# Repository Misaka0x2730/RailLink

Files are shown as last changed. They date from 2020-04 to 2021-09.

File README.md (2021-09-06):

# RailLink
Very compact isolated version of J-Link v9 with fully supported functions. </br>
Isolation based on ADuM4160 (USB2.0 FS isolation) and B0505S-1W (Isolated 5V/0.2A DC-DC). </br>

# Overview
Dimensions(L x W x H, millimeters): 70 x 28 x 15 (probe only); 110 x 35 x 25 (probe with connected adapter). </br>
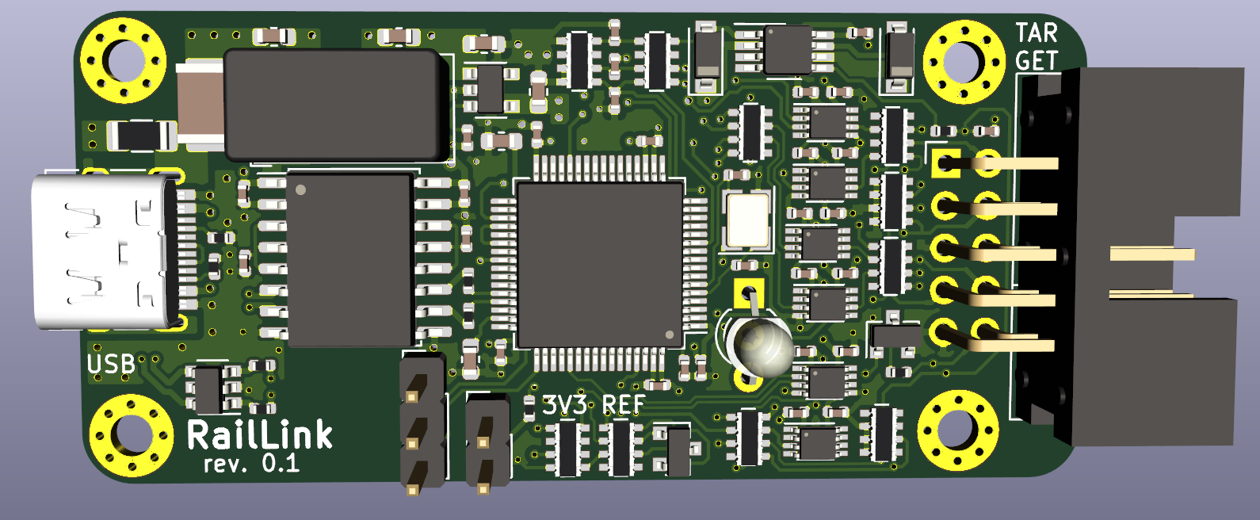
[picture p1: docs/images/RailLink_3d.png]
3d view

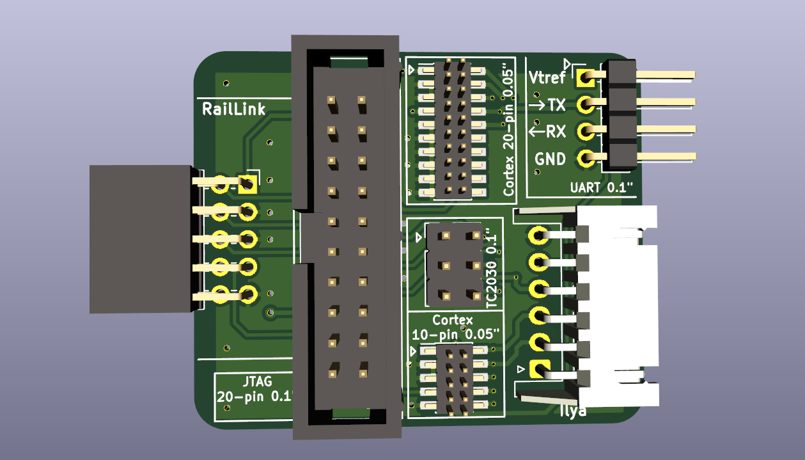
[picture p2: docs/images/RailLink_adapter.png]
3d_adapter


# Probe pinout
RailLink has 10 pin 0.1"(2.54mm) connector compatible with standard ARM 10 pin connector.

<b>RailLink connector</b></br>
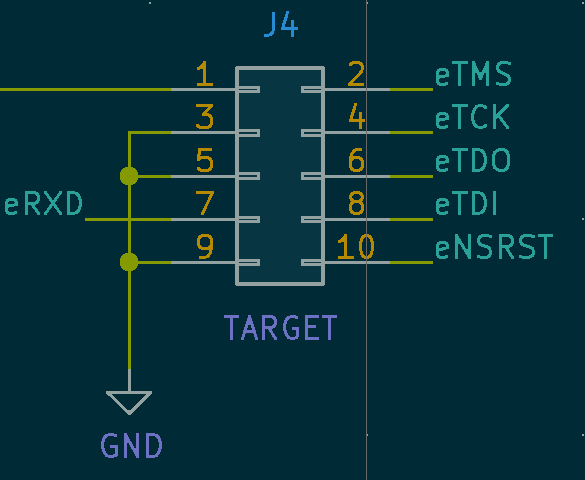
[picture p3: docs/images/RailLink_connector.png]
connector

|Pin|Name |Pin|Name |
|---|---|---|---|
|1  |Vtref  |2  | TMS/SWDIO  |
|3  |GND |4  | TCK/SWCLK  |
|5  |GND |6  | TDO/SWO |
|7  |UART RX|8  | TDI/UART TX|
|9  |GND |10 | ~RESET |

# Adapter pinouts
Adapter has several popular connectors: ARM 10 pin 0.05"(1.27mm), TC2030-IDC-NL  6 pin 0.1"(2.54mm), ARM 20 pin JTAG 0.1"(2.54mm), ARM 20-pin Cortex 0.05"(1.27mm). </br>
In addition, there are two custom connectors: 4 pin UART and CWF-6 (Ilya).

<b>ARM 10 pin 0.05"(1.27mm)</b></br>
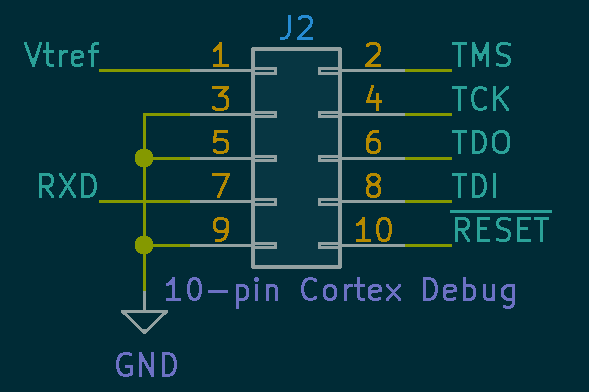
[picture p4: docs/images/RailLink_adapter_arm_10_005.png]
adapter_arm_10_005

|Pin|Name |Pin|Name |
|---|---|---|---|
|1  |Vtref  |2  | TMS/SWDIO  |
|3  |GND |4  | TCK/SWCLK  |
|5  |GND |6  | TDO/SWO |
|7  |UART RX|8  | TDI/UART TX|
|9  |GND |10 | ~RESET |

</br></br><b>TC2030-IDC-NL</b></br>
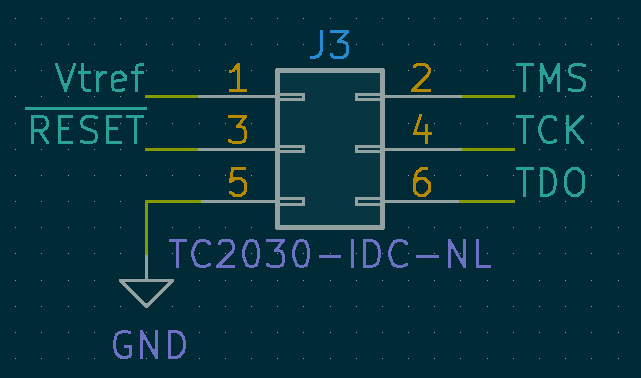
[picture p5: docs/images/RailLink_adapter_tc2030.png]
adapter_tc2030

|Pin|Name |Pin|Name |
|---|---|---|---|
|1  |Vtref  |2  | TMS/SWDIO  |
|3  |~RESET |4  | TCK/SWCLK  |
|5  |GND |6  | TDO/SWO |

</br></br><b>ARM 20 pin JTAG 0.1"(2.54mm)</b></br>
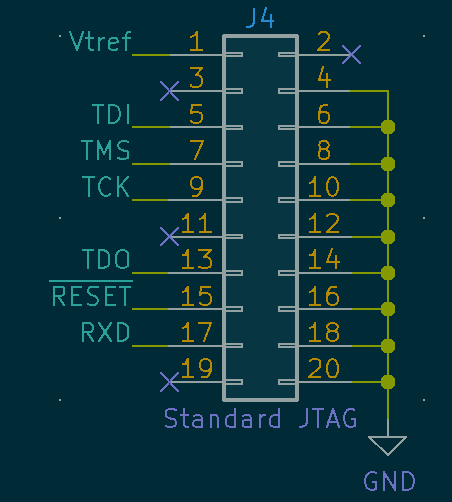
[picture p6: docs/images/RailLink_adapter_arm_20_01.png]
adapter_arm_20_01

|Pin|Name |Pin|Name |
|---|---|---|-----|
|1  |Vtref |2  | NC  |
|3  |NC |4  | GND |
|5  |TDI/UART TX |6  | GND |
|7  |TMS/SWDIO |8  | GND |
|9  |TCK/SWCLK |10 | GND |
|11 |NC |12 | GND |
|13 |TDO/SWO |14 | GND |
|15 |~RESET |16 | GND |
|17 |UART RX |18 | GND |
|19 |NC |20 | GND |

</br></br><b>ARM 20-pin Cortex 0.05"(1.27mm)</b></br>
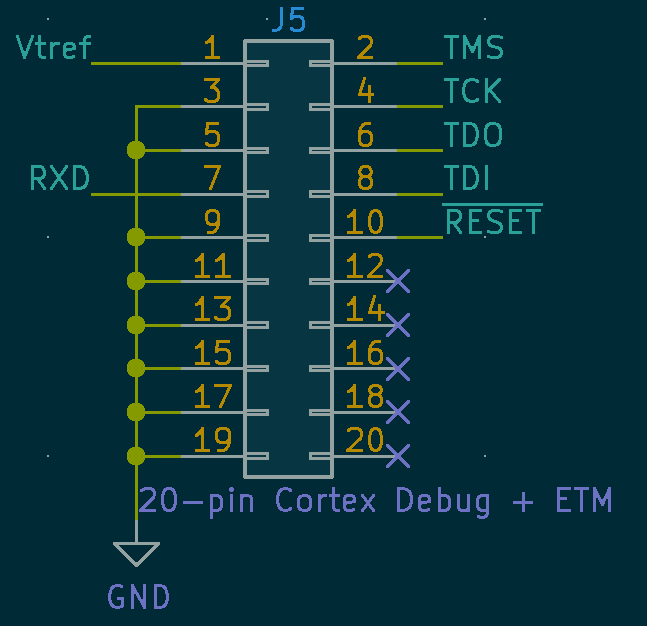
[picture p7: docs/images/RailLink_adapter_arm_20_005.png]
adapter_arm_20_005

|Pin|Name |Pin|Name |
|---|---|---|---|
|1  |Vtref  |2  | TMS/SWDIO  |
|3  |GND |4  | TCK/SWCLK  |
|5  |GND |6  | TDO/SWO |
|7  |UART RX|8  | TDI/UART TX|
|9  |GND |10 | ~RESET |
|11 |GND |12 | NC |
|13 |GND |14 | NC |
|15 |GND |16 | NC |
|17 |GND |18 | NC |
|19 |GND |20 |NC |

</br></br><b>4 pin UART</b></br>
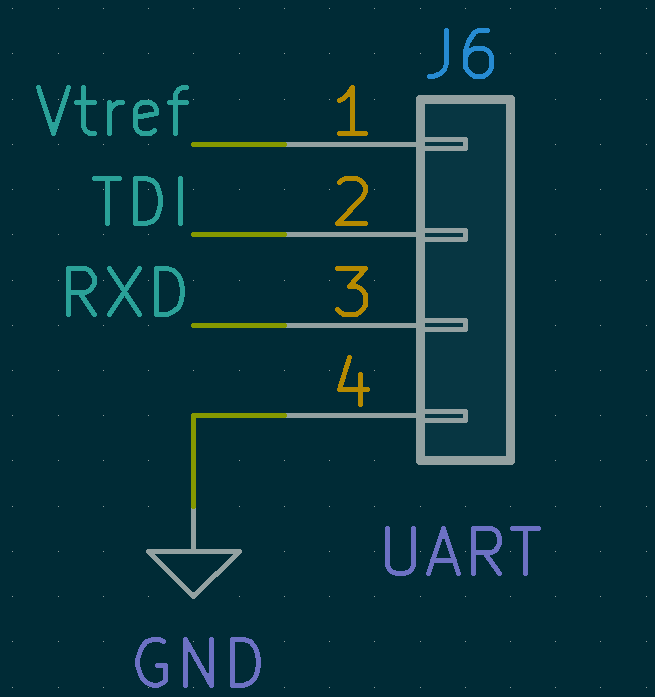
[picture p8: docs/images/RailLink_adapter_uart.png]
adapter_uart

|Pin|Name |
|---|---|
|1  |Vtref |
|2  |TDI/UART TX |
|3  |UART RX |
|4  |GND |

</br></br><b>CWF-6 (Ilya)</b></br>
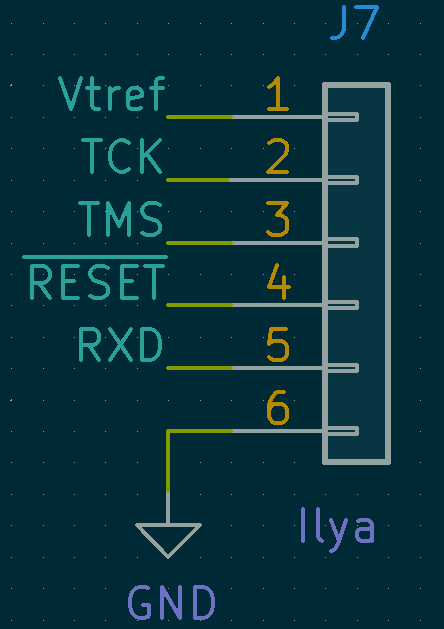
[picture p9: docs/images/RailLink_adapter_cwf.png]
adapter_ilya

|Pin|Name |
|---|---|
|1  |Vtref |
|2  |TCK/SWCLK |
|3  |TMS/SWDIO |
|4  |~RESET |
|3  |UART RX |
|4  |GND |

# Assembly
Most of SMD components are 0402. </br> 
Assembly should be not very difficult even with soldering iron. </br>
But paste soldering with stencil is recommended. </br>
Assembly drawing placed [here](https://github.com/Misaka0x2730/RailLink/blob/master/BOM/ibom.html). </br>
Assembly drawing should be opened in browser. </br>
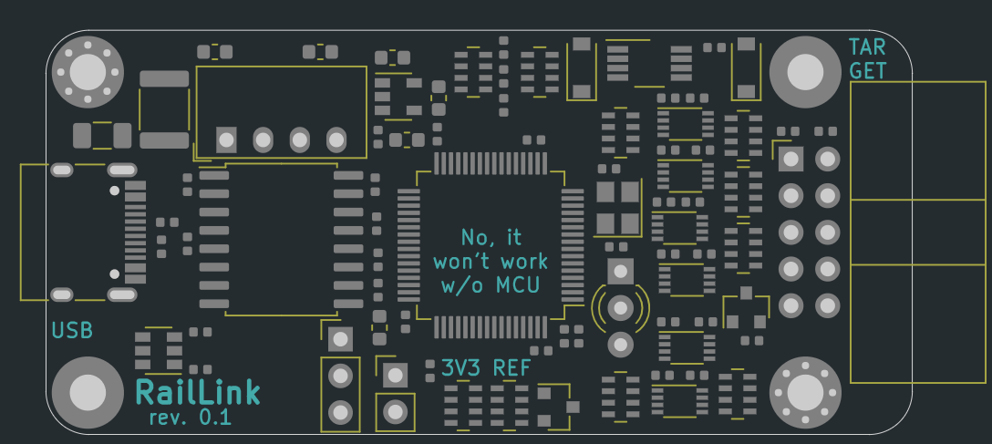
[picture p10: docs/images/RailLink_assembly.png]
assembly


# Programming
 1. Install J-Link software pack.
 2. Load the bootloader
    * <b>ST-LINK way </b>
      1. Install ST-LINK utility
      2. Connect RailLink SWD connector to ST-LINK
      3. Connect ST-LINK to PC
      4. Connect RailLink to PC
      5. Launch ST-LINK utility
      6. Load [this file](https://github.com/Kevincoooool/KS_Diy_Link/blob/master/Jlink_V9/%E5%9B%BA%E4%BB%B6%E5%8D%87%E7%BA%A7%E6%96%B9%E5%BC%8F/JLink-v9_bootloader%E5%9B%BA%E4%BB%B6/bootloa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)
      into MCU.
    * <b>J-Link way</b>
      1. Connect RailLink SWD connector to J-Link
      2. Connect J-Link to PC
      3. Connect RailLink to PC
      4. Start JFlashLite </br> jflashlite_start
      6. Select device - STM32F205RC, select interface - SWD, and speed - 100kHz </br>
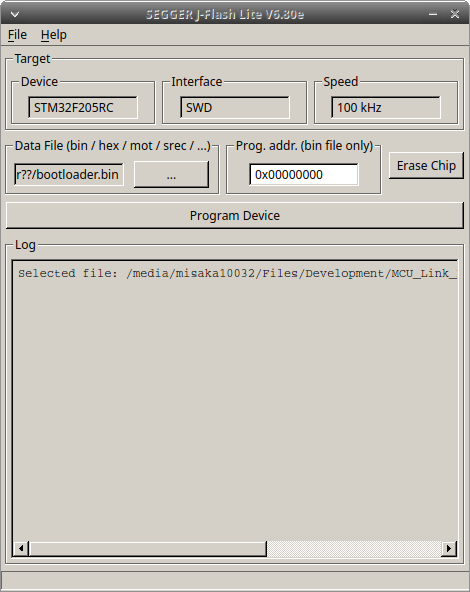
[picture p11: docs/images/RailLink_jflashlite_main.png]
jflashlite_main
      
      8. In Data file field choose [this file](https://github.com/Kevincoooool/KS_Diy_Link/blob/master/Jlink_V9/%E5%9B%BA%E4%BB%B6%E5%8D%87%E7%BA%A7%E6%96%B9%E5%BC%8F/JLink-v9_bootloader%E5%9B%BA%E4%BB%B6/bootloa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)
      9. Click "Program Device" button
      10. Wait until the firmware is loaded;
  3. Disconnect RailLink and JLink from PC.
  4. Connect RailLink to PC.
  5. Launch JLink.exe (JLinkExe on Linux) and agree to firmware restoring.
  6. Wait until firmware is restored.
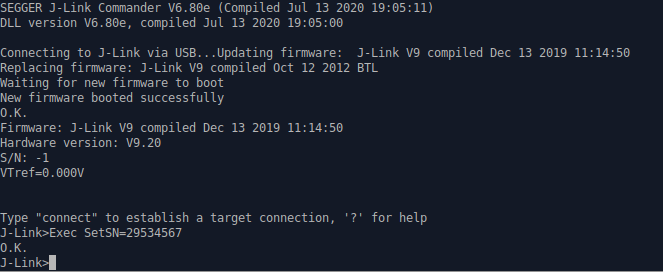
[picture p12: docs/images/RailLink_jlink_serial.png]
jlink_serial
  7. Now RailLink is almost ready for use. Type and run "Exec SetSN=xxxxxxxx", where xxxxxxxx is serial number; 
  8. <b> RailLink is ready for use! </b>
  
<b>PS. Important! </b></br> It's recommended to add following options:
  * Exec AddFeature GDB
  * Exec AddFeature RDI
  * Exec AddFeature FlashBP
  * Exec AddFeature FlashDL
  * Exec AddFeature JFlash
  * Exec AddFeature RDDI </br>
But in latest version (V6.80 at this moment) any of these commands causes "ERROR: Unknown command". </br>
You can install older version (two or more version of JLink software pack can be install on one PC) and try to execute these commands. 
For example, it's working on V6.30.

# License
ohl_logo </br>
This project is licensed under a [CERN Open Hardware Licence Version 2 - Permissive](https://ohwr.org/cern_ohl_p_v2.pdf).

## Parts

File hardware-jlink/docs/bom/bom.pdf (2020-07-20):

Sheet1
Количество устройств | 48
Обозначение | Партнамбер | Тип | Количество на 1 устройство Всего в наличии Запас | Примечания
Полностью в наличии
C1 | 202S43W472KV4E | Конденсатор 1812 4.7нФ/2кВ | 1 | 55 | 7
C11, C14, C18 | 0402B103K500NT | Конденсатор 0402 10нФ | 3 | 200 | 56
C13, C17 | CL10A225KP8NNNC | Конденсатор 0603 2.2мкФ | 2 | 150 | 54
C2, C15 | CL10A475KP8NNNC | Конденсатор 0603 4.7мкФ | 2 | 150 | 54
| 0402B104K160CT | Конденсатор 0402 0.1мкФ | 25 | 2000
| | | | | 800
C7 | GRM188R61A106ME69D | Конденсатор 0603 10мкФ | 1 | 100 | 52
C8 | CL10B105KP8NNNC | Конденсатор 0603 1мкФ | 1 | 100 | 52
C9, C10 | C1005NP0180KGT | Конденсатор 0402 18пФ | 2 | 300 | 204
D1 | TJ-L3FYTXHMCYLC2R2G-A5 | Двухцветный светодиод 3мм ОА | 1 | 58 | 10
J1 | TYPE-C-31-M-12 | Разъём USB2.0 Type-C | 1 | 60 | 12
J2 | PLS-3 | 3-х контактная гребёнка 2.54 мм | 1 | 80 | 32 Отломать от 40-контактной
J3 | PLS-2 | Джампер 2.54 мм | 1 | 80 | 32 Отломать от 40-контактной
J4 | C9140 | IDC-10R – угловой | 1 | 55 | 7
Q1 | IRLML2502 | N-Ch MOSFET | 1 | 100 | 52
Q2 | IRLML6402 | P-Ch MOSFET | 1 | 100 | 52
R1 | 1206W4J0105T5E | Резистор 1206 1МОм | 1 | 100 | 52
R2, R5, R6, R7 | 0402WGF220JTCE | Резистор 0402 22Ом | 4 | 300 | 108
R3, R4, R9 | 0402WGJ0512TCE | Резистор 0402 5.1кОм | 3 | 300 | 156
R8 | 0402WGJ0510TCE | Резистор 0402 51Ом | 1 | 100 | 52
R10 | RC0402FR-071KL | Резистор 0402 1кОм | 1 | 97 | 49
RN1, RN5, RN6, RN7 | 4D03WGJ0471T5E | Резисторная сборка 4x0603 470Ом | 4 | 250 | 58
RN2, RN3, RN4 | 4D03WGJ0103T5E | Резисторная сборка 4x0603 10кОм | 3 | 150 | 6
RN8 | 4D03WGJ0101T5E | Резисторная сборка 4x0603 100Ом | 1 | 100 | 52
RN9, RN10 | 4D03WGJ0224T5E | Резисторная сборка 4x0603 220кОм | 2 | 197 | 101
Y1 | X322512MSB4SI | Кварцевый резонатор 3225 12МГц | 1 | 60 | 12
| C2337 | Гребёнка, шаг 2.54 мм, 40 контактов (для J2 и j3)
| | Частично в наличии
D2, D3 | MBR0530 | Диод Шоттки SOD-123 | 2 | 79 | -17
U3 | ADUM4160BRWZ | Изолятор USB2.0 FS | 1 | 2 | -46
U2 | B0505S-1W | Изолированный DC-DC 5В 1Вт | 1 | 4 | -44
| | Вообще нет в наличии
U4 | LK112M33TR | LDO SOT-23-5 3.3В 150мА | 1 | | -48
U12 | MCP6002-I/MS | Rail-to-Rail ОУ VSSOP-8 | 1 | | -48
U6, U7, U8, U9, U10, U11 SN74LVC2T45DCUR | Буфер 1.2В-5.5В VSSOP-8 | 6 | -288
U5 | STM32F205RCT6 | Микроконтроллер Cortex-M3 LQFP-64 | 1 | | -48
U1 | USBLC6-2SC6 | ESD-защита USB SOT-23-6 | 1 | | -48
| | Переходник
J1 | LCSC: A2541HWR-2x5P (без ключа) | IDC-10 Female Right Angle | 1 | | -48
| | IDC-10 Female Right Angle
J2 | 20021121-00010C4LF | Штыревой разъём, шаг 1.27 мм, 2 ряда x 5 контактов, SMD | 1 | | -48
J3 | C65114 | Штыревой разъём, шаг 2.54мм, 2 ряда x 3 контакта | 1 | | -48
J4 | C3405 (BH-20) | Штыревой разъём, шаг 2.54 мм, 2 ряда x 10 контактов, с ключом | 1 | | -48
J5 | 20021121-00020C4LF | Штыревой разъём, шаг 1.27 мм, 2 ряда x 10 контактов, SMD | 1 | | -48
J6 | C91552 (PLS-4R) | Угловая гребёнка, шаг 2.54 мм, 4 контакта | 1 | | -48
J7 | CWF-6R (S6B-XH-A) | Разъём, шаг 2.5 мм, плата - провод | 1 | | -48
| MTFC16-10YW (IDC-10F) | Розетка на кабель, шаг 2.54 мм, 2 ряда x 5 контактов | 2 | | -96
| | Шлейф плоский, шаг 2.54 мм, 10 контактов, 10 сантиметров | 0,1 | | -4,8

C3, C4, C5, C6, C12, C16,
C19, C20, C21, C22, C23,
C24, C25, C26, C27, C28,
C29, C30, C31, C32, C33,
C34, C35, C36, C37

Аналог: SFH11-PBPC-D05-RA-BK (с ключом)

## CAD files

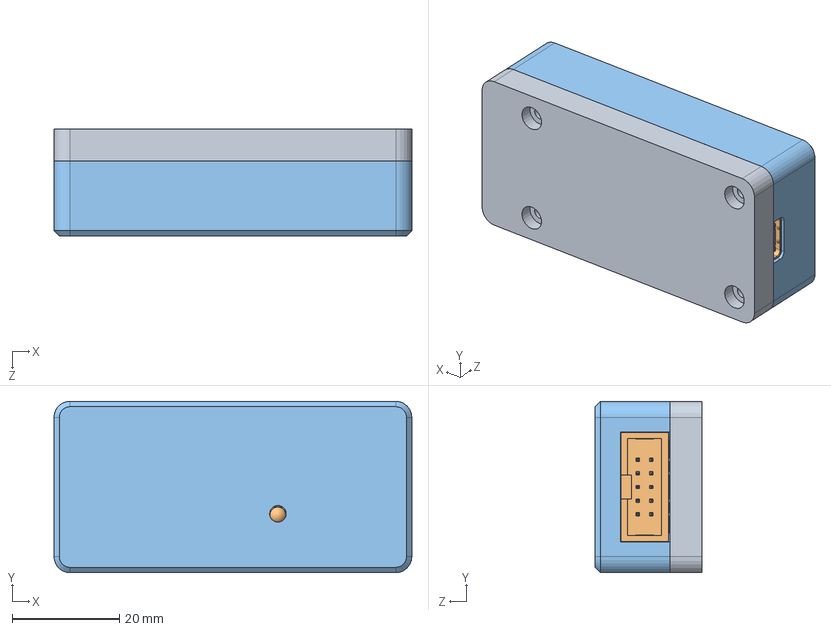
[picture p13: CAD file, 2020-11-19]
mechanical-case/source-sw2019/asm-jlink-case.SLDASM
66.8 x 32.0 x 20.0 mm
jlink-case-bottom
jlink
jlink-case-top

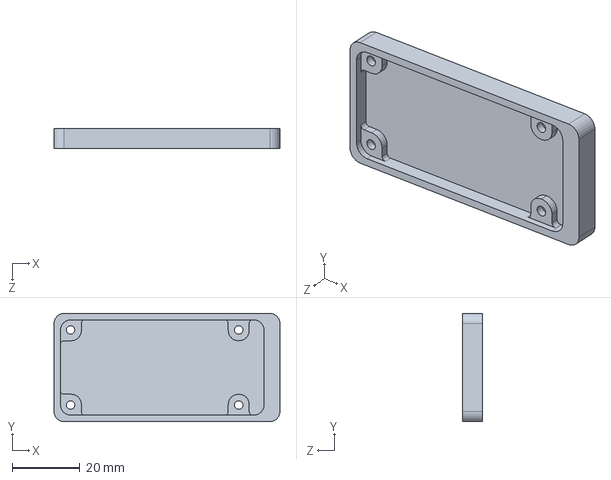
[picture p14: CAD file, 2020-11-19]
mechanical-case/source-sw2019/jlink-case-bottom.SLDPRT
66.8 x 32.0 x 6.00 mm

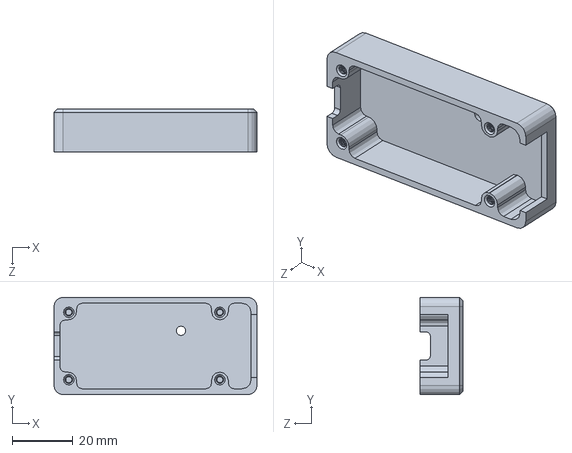
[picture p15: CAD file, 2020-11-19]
mechanical-case/source-sw2019/jlink-case-top.SLDPRT
66.8 x 32.0 x 14.0 mm

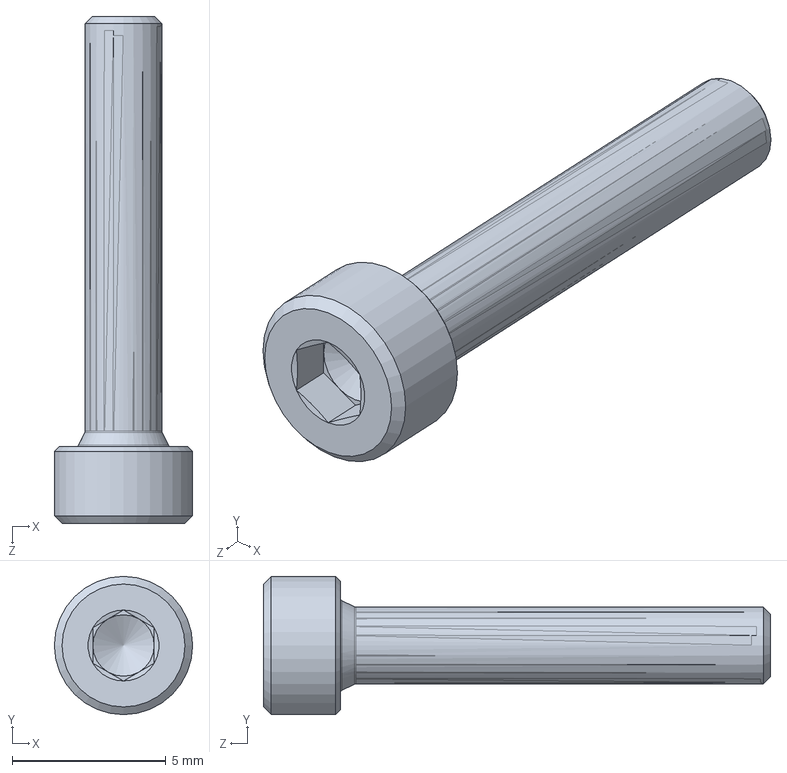
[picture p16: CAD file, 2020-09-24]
mechanical-case/source-sw2019/M2.5x14.SLDPRT
4.50 x 4.50 x 16.5 mm

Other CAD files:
mechanical-case/step-model/jlink-case-bottom.STEP

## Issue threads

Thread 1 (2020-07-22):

Wrong LED connection.

Misaka0x2730, 2020-07-22:
<b>Problem:</b> LED cathodes are connected to MCU throughout 470Ohm resistor arrays. But many of bi-color LEDs have big difference between colors luminous intensity. For example, TJ-L3FYTXHMCYLC2R2G-A5:
Red - 100 mcd max.
Green - 1500 mcd max.
Difference is 15(!) times! Green LED current should be less many times.
But resistor array resistance can't be increased, because line and in\out capacitance with greater resistance will reduce max. interface frequency.
<b>Solution:</b> Every cathode should be connected to MCU throughout own resistor.
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

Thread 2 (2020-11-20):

А чего куда про коллективную закупку?

LinFor, 2020-11-20:
Интересна 1 штука без корпуса :)

RedCommissary, 2020-11-20:
Коллективная закупка прошла, но вообще все подобные события происходят тут: https://t.me/proHardware

LinFor, 2020-11-23:
Жаль :( В чате флуда очень много. Канал бы с важным.

Closed 2020-11-23.

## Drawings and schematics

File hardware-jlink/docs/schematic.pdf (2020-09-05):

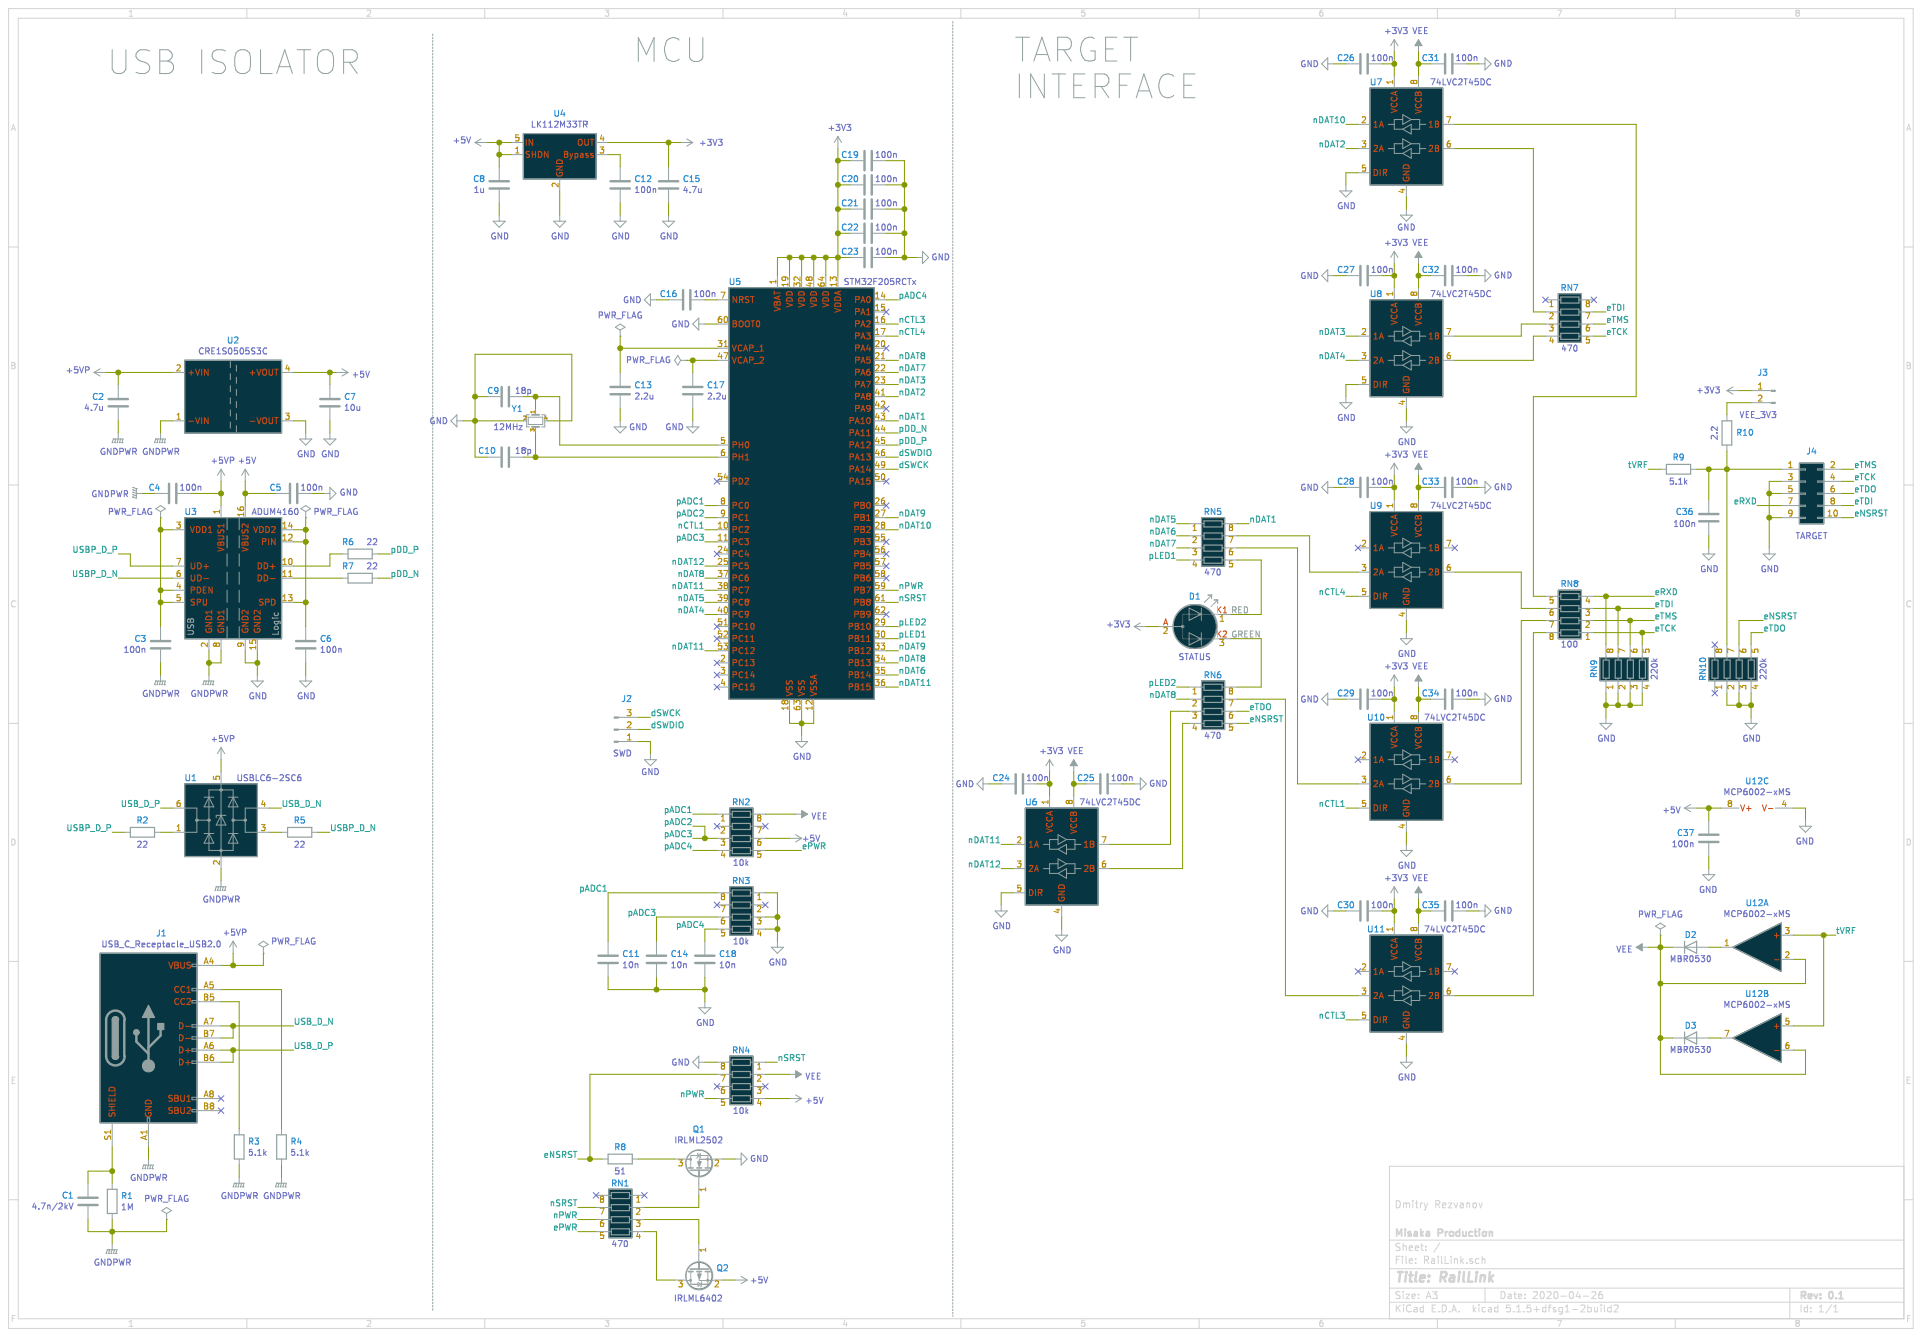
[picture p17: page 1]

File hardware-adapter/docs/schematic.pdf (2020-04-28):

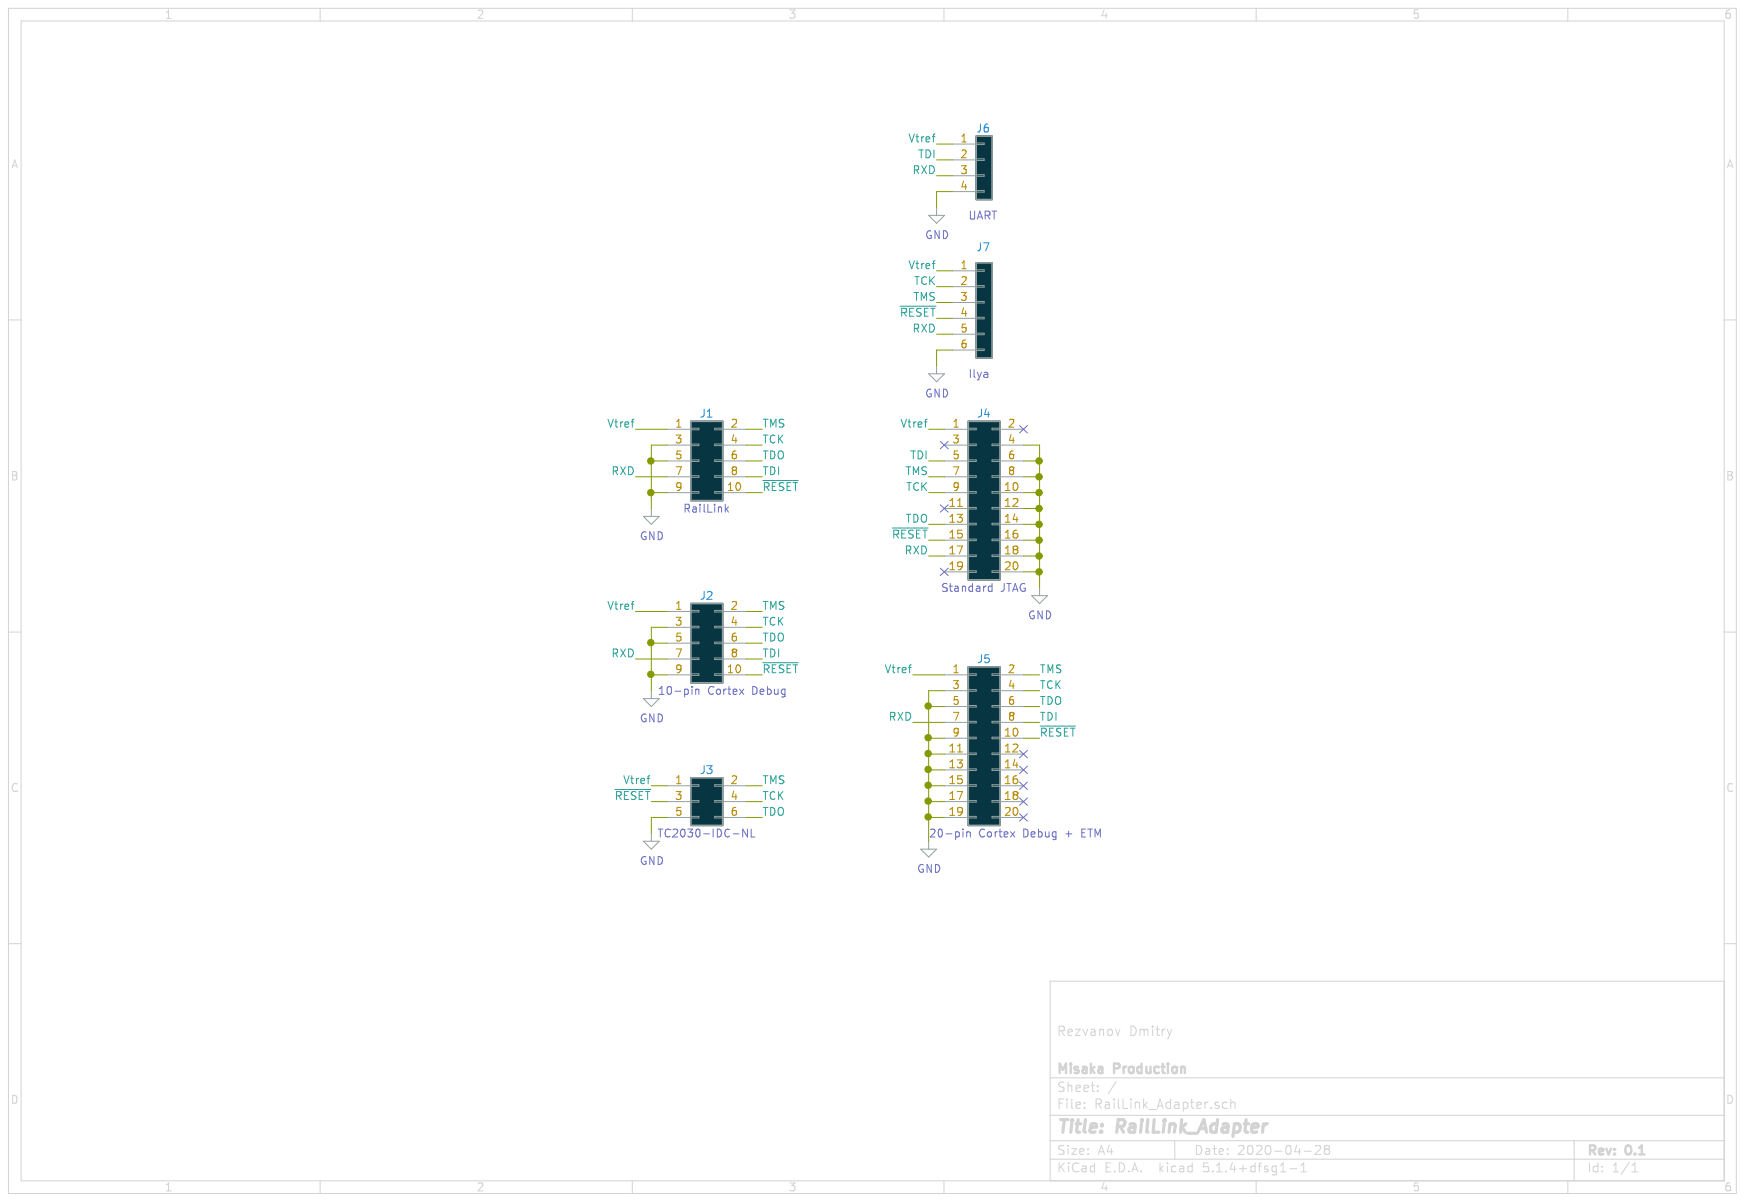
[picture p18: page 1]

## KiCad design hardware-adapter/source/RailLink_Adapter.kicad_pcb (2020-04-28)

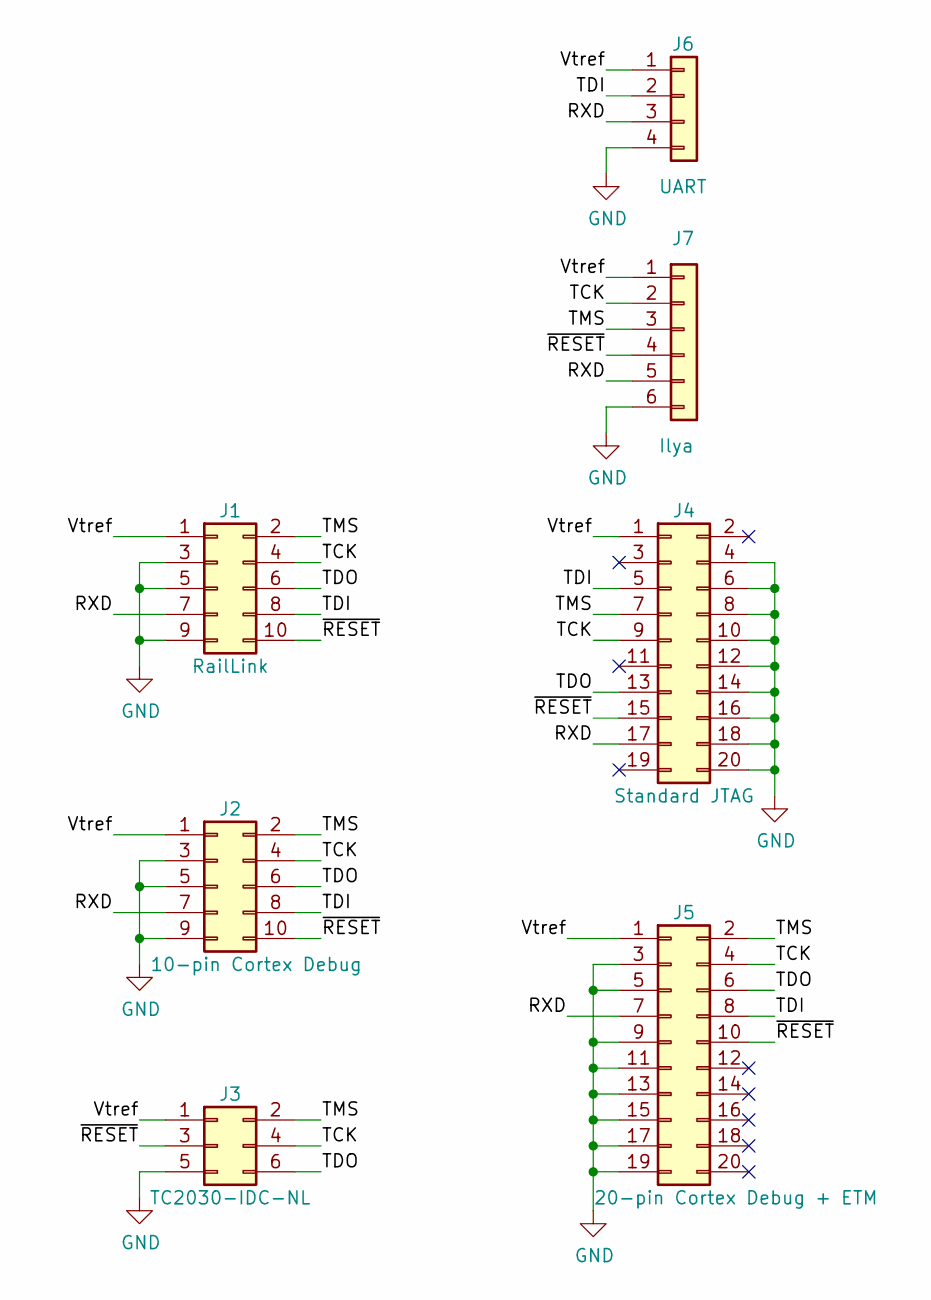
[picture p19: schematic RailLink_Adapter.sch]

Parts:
J1: RailLink; PinSocket_2x05_P2.54mm_Horizontal
J2: 10-pin Cortex Debug; PinHeader_2x05_P1.27mm_Vertical_SMD
J3: TC2030-IDC-NL; PinHeader_2x03_P2.54mm_Vertical
J4: Standard JTAG; IDC-Header_2x10_P2.54mm_Vertical
J5: 20-pin Cortex Debug + ETM; PinHeader_2x10_P1.27mm_Vertical_SMD
J6: UART; PinHeader_1x04_P2.54mm_Horizontal
J7: Ilya; JST_XH_S6B-XH-A_1x06_P2.50mm_Horizontal

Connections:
/RXD: J1.7, J2.7, J4.17, J5.7, J6.3, J7.5
/TCK: J1.4, J2.4, J3.4, J4.9, J5.4, J7.2
/TDI: J1.8, J2.8, J4.5, J5.8, J6.2
/TDO: J1.6, J2.6, J3.6, J4.13, J5.6
/TMS: J1.2, J2.2, J3.2, J4.7, J5.2, J7.3
/Vtref: J1.1, J2.1, J3.1, J4.1, J5.1, J6.1, J7.1
/~RESET: J1.10, J2.10, J3.3, J4.15, J5.10, J7.4
GND: J1.3, J1.5, J1.9, J2.3, J2.5, J2.9, J3.5, J4.4, J4.6, J4.8, J4.10, J4.12, J4.14, J4.16, J4.18, J4.20, J5.3, J5.5, J5.9, J5.11, J5.13, J5.15, J5.17, J5.19, J6.4, J7.6

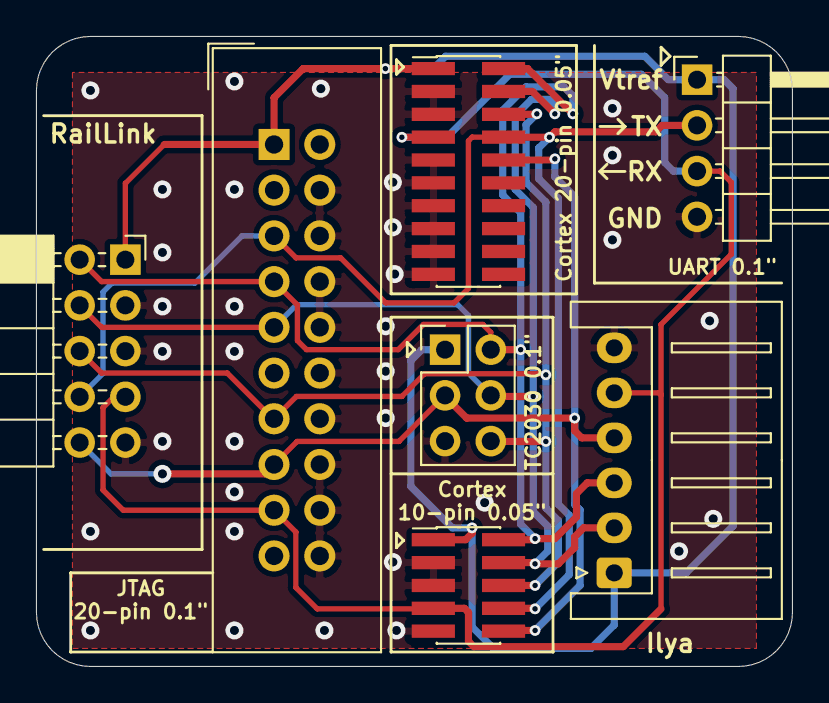
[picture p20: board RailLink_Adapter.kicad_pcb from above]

Board: 2 copper layers, 42.0 x 35.0 mm, 7 parts (0 on the bottom side), 8 nets.

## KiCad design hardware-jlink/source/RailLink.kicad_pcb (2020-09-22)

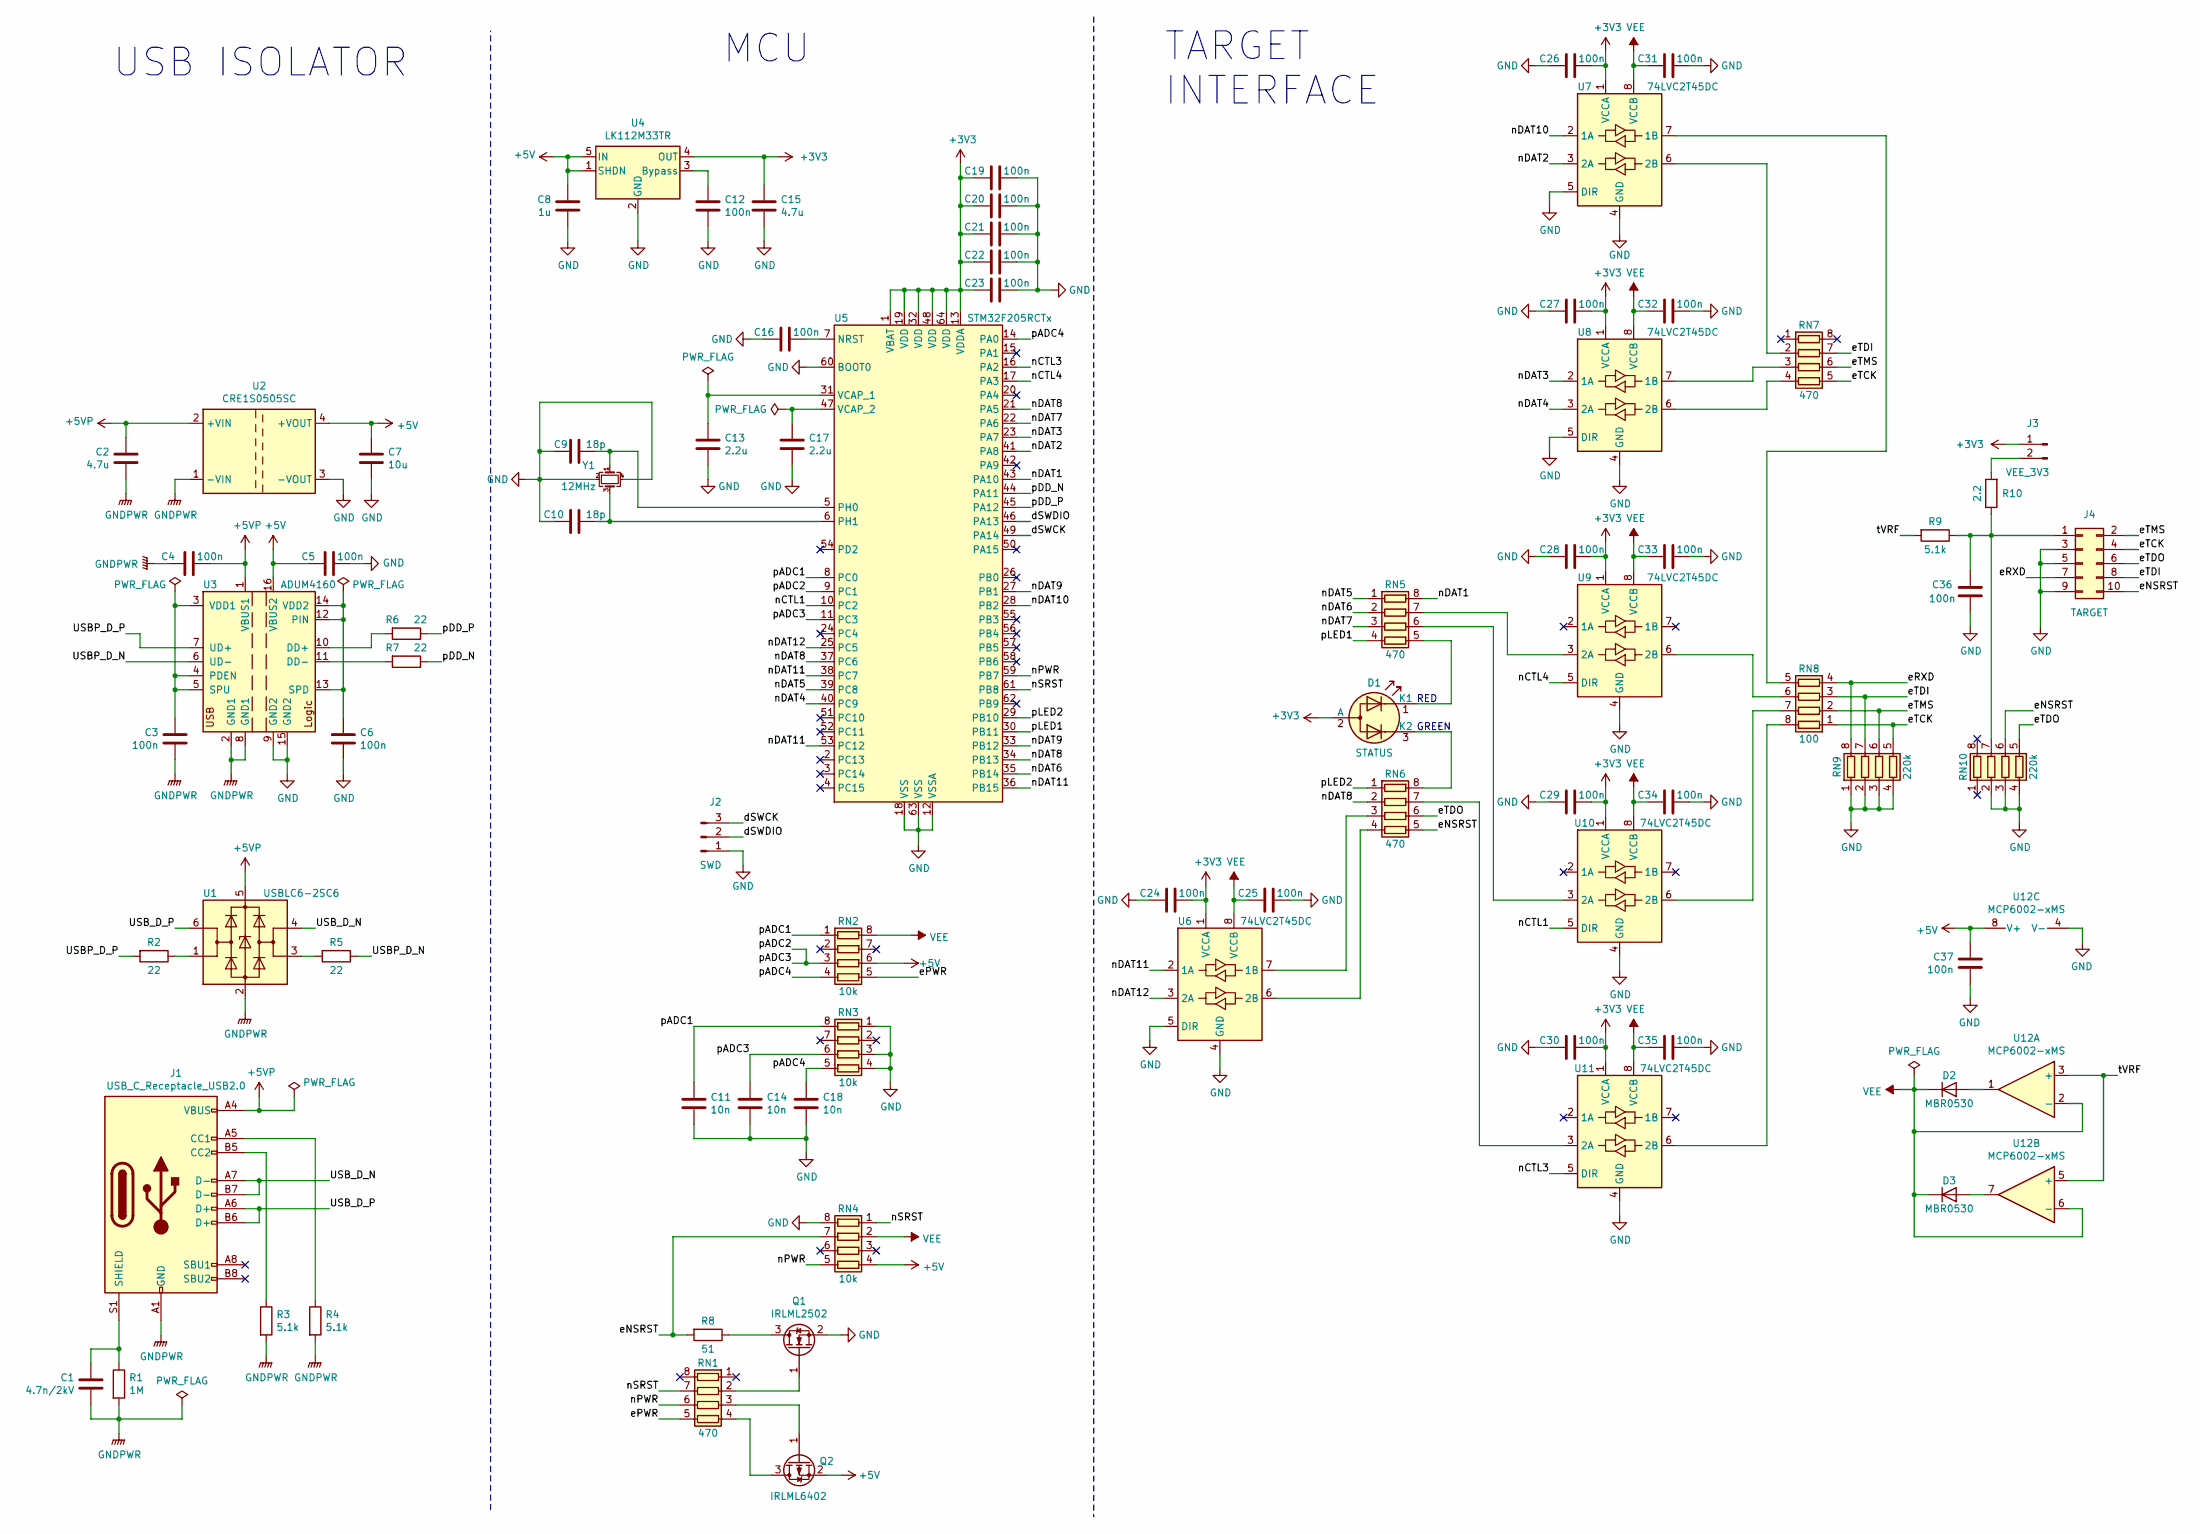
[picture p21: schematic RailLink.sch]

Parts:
C1: 4.7n/2kV; C_1812_4532Metric; Part Number 202S43W472KV4E
C2, C15: 4.7u; C_0603_1608Metric; Part Number CL10A475KP8NNNC
C3, C4, C5, C6, C12, C16, C19, C20, C21, C22, C23, C24, C25, C26, C27, C28, C29, C30, C31, C32, C33, C34, C35, C36, C37: 100n; C_0402_1005Metric; Part Number 0402B104K160CT
C7: 10u; C_0603_1608Metric; Part Number GRM188R61A106ME69D
C8: 1u; C_0603_1608Metric; Part Number CL10B105KP8NNNC
C9, C10: 18p; C_0402_1005Metric; Part Number C1005NP0180KGT
C11, C14, C18: 10n; C_0402_1005Metric; Part Number 0402B103K500NT
C13, C17: 2.2u; C_0603_1608Metric; Part Number CL10A225KP8NNNC
D1: STATUS; LED_D3.0mm-3; Part Number TJ-L3FYTXHMCYLC2R2G-A5
D2, D3: MBR0530; D_SOD-123; Part Number MBR0530
J1: USB_C_Receptacle_USB2.0; USB_C_Receptacle_HRO_TYPE-C-31-M-12; Part Number TYPE-C-31-M-12
J2: SWD; PinHeader_1x03_P2.54mm_Vertical; Part Number C2337
J3: VEE_3V3; PinHeader_1x02_P2.54mm_Vertical; Part Number C2337
J4: TARGET; IDC-Header_2x05_P2.54mm_Horizontal; Part Number C9140
Q1: IRLML2502; SOT-23; Part Number IRLML2502
Q2: IRLML6402; SOT-23; Part Number IRLML6402
R1: 1M; R_1206_3216Metric; Part Number 1206W4J0105T5E
R2, R5, R6, R7: 22; R_0402_1005Metric; Part Number 0402WGF220JTCE
R3, R4, R9: 5.1k; R_0402_1005Metric; Part Number 0402WGJ0512TCE
R8: 51; R_0402_1005Metric; Part Number 0402WGJ0510TCE
R10: 2.2; R_0402_1005Metric; Part Number RC0402FR-071KL
RN1, RN5, RN6, RN7: 470; R_Array_Concave_4x0603; Part Number 4D03WGJ0471T5E
RN2, RN3, RN4: 10k; R_Array_Concave_4x0603; Part Number 4D03WGJ0103T5E
RN8: 100; R_Array_Concave_4x0603; Part Number 4D03WGJ0101T5E
RN9, RN10: 220k; R_Array_Concave_4x0603; Part Number 4D03WGJ0224T5E
U1: USBLC6-2SC6; SOT-23-6; Part Number USBLC6-2SC6
U2: CRE1S0505SC; Converter_DCDC_muRata_CRE1xxxxxxSC_THT; Part Number B0505S-1W
U3: ADUM4160; SOIC-16W_7.5x10.3mm_P1.27mm; Part Number ADUM4160BRWZ-RL
U4: LK112M33TR; SOT-23-5; Part Number LK112M33TR
U5: STM32F205RCTx; LQFP-64_10x10mm_P0.5mm; Part Number STM32F205RCT6
U6, U7, U8, U9, U10, U11: 74LVC2T45DC; VSSOP-8_2.3x2mm_P0.5mm; Part Number SN74LVC2T45DCUR
U12: MCP6002-xMS; VSSOP-8_3.0x3.0mm_P0.65mm; Part Number MCP6002-I/MS
Y1: 12MHz; Crystal_SMD_3225-4Pin_3.2x2.5mm; Part Number X322512MSB4SI

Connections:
+3V3: C15.2, C19.2, C20.2, C21.2, C22.2, C23.2, C24.1, C26.1, C27.1, C28.1, C29.1, C30.1, D1.2 (A), J3.1, U4.4 (OUT), U5.1 (VBAT), U5.13 (VDDA), U5.19 (VDD), U5.32 (VDD), U5.48 (VDD), U5.64 (VDD), U6.1 (VCCA), U7.1 (VCCA), U8.1 (VCCA), U9.1 (VCCA), U10.1 (VCCA), U11.1 (VCCA)
+5V: C5.1, C7.2, C8.2, C37.1, Q2.2 (S), RN2.6 (R3.2), RN4.4 (R4.1), U2.4 (+VOUT), U3.16 (VBUS2), U4.1 (SHDN), U4.5 (IN), U12.8 (V+)
+5VP: C2.2, C4.2, J1.A4 (VBUS), J1.A9 (VBUS), J1.B4 (VBUS), J1.B9 (VBUS), U1.5 (VBUS), U2.2 (+VIN), U3.1 (VBUS1)
/USBP_D_N: R5.1, U3.6 (UD-)
/USBP_D_P: R2.2, U3.7 (UD+)
/USB_D_N: J1.A7 (D-), J1.B7 (D-), U1.4 (I/O2)
/USB_D_P: J1.A6 (D+), J1.B6 (D+), U1.6 (I/O1)
/dSWCK: J2.3, U5.49 (PA14)
/dSWDIO: J2.2, U5.46 (PA13)
/eNSRST: J4.10, R8.2, RN4.7 (R2.2), RN6.5 (R4.2), RN10.6 (R3.2)
/ePWR: RN1.5 (R4.2), RN2.5 (R4.2)
/eRXD: J4.7, RN8.4 (R4.1), RN9.8 (R1.2)
/eTCK: J4.4, RN7.5 (R4.2), RN8.1 (R1.1), RN9.5 (R4.2)
/eTDI: J4.8, RN7.7 (R2.2), RN8.3 (R3.1), RN9.7 (R2.2)
/eTDO: J4.6, RN6.6 (R3.2), RN10.5 (R4.2)
/eTMS: J4.2, RN7.6 (R3.2), RN8.2 (R2.1), RN9.6 (R3.2)
/nCTL1: U5.10 (PC2), U10.5 (DIR)
/nCTL3: U5.16 (PA2), U11.5 (DIR)
/nCTL4: U5.17 (PA3), U9.5 (DIR)
/nDAT1: RN5.8 (R1.2), U5.43 (PA10)
/nDAT2: U5.41 (PA8), U7.3 (2A)
/nDAT3: U5.23 (PA7), U8.2 (1A)
/nDAT4: U5.40 (PC9), U8.3 (2A)
/nDAT5: RN5.1 (R1.1), U5.39 (PC8)
/nDAT6: RN5.2 (R2.1), U5.35 (PB14)
/nDAT7: RN5.3 (R3.1), U5.22 (PA6)
/nDAT8: RN6.2 (R2.1), U5.21 (PA5), U5.34 (PB13), U5.37 (PC6)
/nDAT9: U5.27 (PB1), U5.33 (PB12)
/nDAT10: U5.28 (PB2), U7.2 (1A)
/nDAT11: U5.36 (PB15), U5.38 (PC7), U5.53 (PC12), U6.2 (1A)
/nDAT12: U5.25 (PC5), U6.3 (2A)
/nPWR: RN1.6 (R3.2), RN4.5 (R4.2), U5.59 (PB7)
/nSRST: RN1.7 (R2.2), RN4.1 (R1.1), U5.61 (PB8)
/pADC1: C11.1, RN2.1 (R1.1), RN3.8 (R1.2), U5.8 (PC0)
/pADC2: C14.1, RN2.3 (R3.1), RN3.6 (R3.2), U5.9 (PC1), U5.11 (PC3)
/pADC4: C18.1, RN2.4 (R4.1), RN3.5 (R4.2), U5.14 (PA0)
/pDD_N: R7.1, U5.44 (PA11)
/pDD_P: R6.1, U5.45 (PA12)
/pLED1: RN5.4 (R4.1), U5.30 (PB11)
/pLED2: RN6.1 (R1.1), U5.29 (PB10)
/tVRF: R9.2, U12.3 (+), U12.5 (+)
GND: C5.2, C6.1, C7.1, C8.1, C9.2, C10.1, C11.2, C12.1, C13.2, C14.2, C15.1, C16.2, C17.2, C18.2, C19.1, C20.1, C21.1, C22.1, C23.1, C24.2, C25.1, C26.2, C27.2, C28.2, C29.2, C30.2, C31.1, C32.1, C33.1, C34.1, C35.1, C36.2, C37.2, J2.1, J4.3, J4.5, J4.9, Q1.2 (S), RN3.1 (R1.1), RN3.3 (R3.1), RN3.4 (R4.1), RN4.8 (R1.2), RN9.1 (R1.1), RN9.2 (R2.1), RN9.3 (R3.1), RN9.4 (R4.1), RN10.2 (R2.1), RN10.3 (R3.1), RN10.4 (R4.1), U2.3 (-VOUT), U3.9 (GND2), U3.15 (GND2), U4.2 (GND), U5.12 (VSSA), U5.18 (VSS), U5.60 (BOOT0), U5.63 (VSS), U6.4 (GND), U6.5 (DIR), U7.4 (GND), U7.5 (DIR), U8.4 (GND), U8.5 (DIR), U9.4 (GND), U10.4 (GND), U11.4 (GND), U12.4 (V-), Y1.2, Y1.4
GNDPWR: C1.1, C2.1, C3.1, C4.1, J1.A1 (GND), J1.A12 (GND), J1.B1 (GND), J1.B12 (GND), R1.2, R3.2, R4.2, U1.2 (GND), U2.1 (-VIN), U3.2 (GND1), U3.8 (GND1)
unnamed: C1.2, J1.S1 (SHIELD), R1.1
unnamed: C3.2, U3.3 (VDD1), U3.4 (PDEN), U3.5 (SPU)
unnamed: C6.2, U3.12 (PIN), U3.13 (SPD), U3.14 (VDD2)
unnamed: C9.1, U5.5 (PH0), Y1.1
unnamed: C10.2, U5.6 (PH1), Y1.3
unnamed: C12.2, U4.3 (Bypass)
unnamed: C13.1, U5.31 (VCAP_1)
unnamed: C16.1, U5.7 (NRST)
unnamed: C17.1, U5.47 (VCAP_2)
unnamed: C36.1, J4.1, R9.1, R10.1, RN10.7 (R2.2)
unnamed: D1.1 (K1), RN5.5 (R4.2)
unnamed: D1.3 (K2), RN6.8 (R1.2)
unnamed: D2.2 (A), U12.1
unnamed: D3.2 (A), U12.7
unnamed: J1.A5 (CC1), R4.1
unnamed: J1.B5 (CC2), R3.1
unnamed: J3.2, R10.2
unnamed: Q1.1 (G), RN1.2 (R2.1)
unnamed: Q1.3 (D), R8.1
unnamed: Q2.1 (G), RN1.3 (R3.1)
unnamed: Q2.3 (D), RN1.4 (R4.1)
unnamed: R2.1, U1.1 (I/O1)
unnamed: R5.2, U1.3 (I/O2)
unnamed: R6.2, U3.10 (DD+)
unnamed: R7.2, U3.11 (DD-)
unnamed: RN5.6 (R3.2), U10.3 (2A)
unnamed: RN5.7 (R2.2), U9.3 (2A)
unnamed: RN6.3 (R3.1), U6.7 (1B)
unnamed: RN6.4 (R4.1), U6.6 (2B)
unnamed: RN6.7 (R2.2), U11.3 (2A)
unnamed: RN7.2 (R2.1), U7.6 (2B)
unnamed: RN7.3 (R3.1), U8.7 (1B)
unnamed: RN7.4 (R4.1), U8.6 (2B)
unnamed: RN8.5 (R4.2), U7.7 (1B)
unnamed: RN8.6 (R3.2), U9.6 (2B)
unnamed: RN8.7 (R2.2), U10.6 (2B)
unnamed: RN8.8 (R1.2), U11.6 (2B)
VEE: C25.2, C31.2, C32.2, C33.2, C34.2, C35.2, D2.1 (K), D3.1 (K), RN2.8 (R1.2), RN4.2 (R2.1), U6.8 (VCCB), U7.8 (VCCB), U8.8 (VCCB), U9.8 (VCCB), U10.8 (VCCB), U11.8 (VCCB), U12.2 (-), U12.6 (-)

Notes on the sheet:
USB ISOLATOR
MCU
TARGET INTERFACE
RED
GREEN

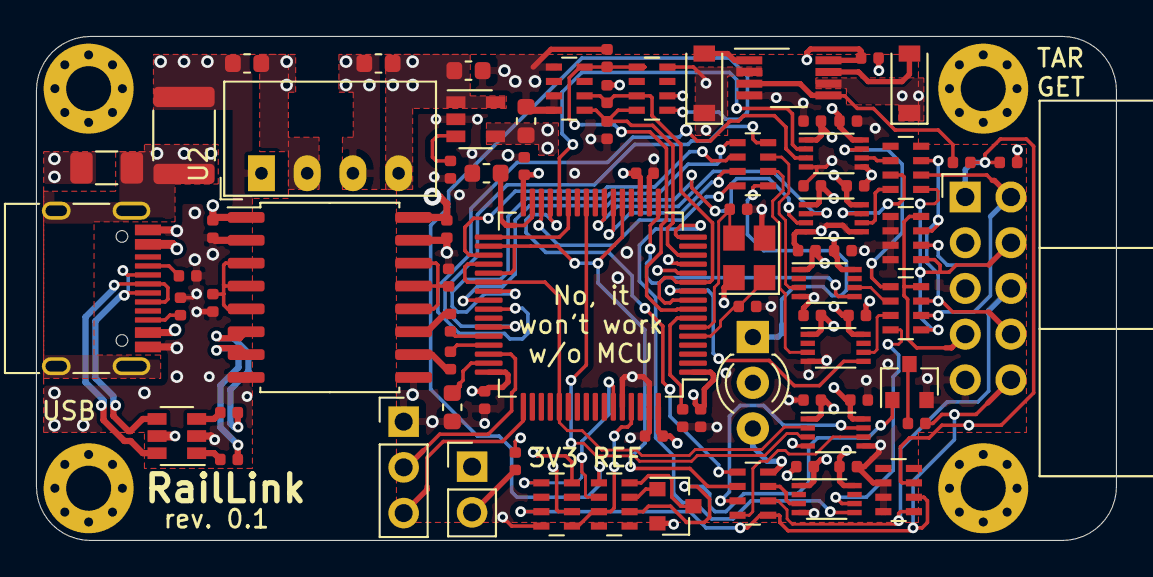
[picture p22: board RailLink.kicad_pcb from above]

Board: 4 copper layers, 60.0 x 28.0 mm, 79 parts (0 on the bottom side), 81 nets.

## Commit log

2020-04-26 Initial commit. Release first pcb revision.
    [RailLink-B_Cu.gbr, RailLink-B_Mask.gbr, RailLink-Edge_Cuts.gbr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]
2020-04-26 Added short-circuit protection on tVRF net
    [RailLink-B_Cu.gbr, RailLink-B_Mask.gbr, RailLink-Edge_Cuts.gbr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]
2020-04-26 Added STEP file for PCB
    [RailLink.kicad_pcb]
2020-04-26 Added STEP file for USB Type-C connector
    [User Library-USB - C.STEP]
2020-04-28 1. Increased clearance from USB Type-C to board edge. 2. 2 status LEDs changed to single 3mm THT.
    [RailLink_Adapter-B_Cu.gbr, RailLink_Adapter-B_Mask.gbr, RailLink_Adapter-B_SilkS.gbr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]
2020-04-28 Added missed files
    [RailLink-B_Cu.gbr, RailLink-B_Mask.gbr, RailLink-Edge_Cuts.gbr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]
2020-04-28 Some minor changes before PCB ordering
    [RailLink-B_Cu.gbr, RailLink-B_Mask.gbr, RailLink-Edge_Cuts.gbr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]
2020-04-28 Added bottom sikscreen layer
    [RailLink-B_Cu.gbr, RailLink-B_Mask.gbr, RailLink-B_SilkS.gbr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]
2020-07-18 Changed op amp to MCP6002 and R10 value to 1k. Added component list for probe and adapter.
    [Component availability.ods, RailLink.kicad_pcb, RailLink.sch]
2020-07-19 Added 3D and assembly images
2020-07-20 Swapped led's cathodes. Updated component availability
    [Component availability.ods, RailLink.sch]
2020-07-22 Add adapter connectors images
2020-09-05 Fixed R10 value (1kOhm -> 2.2Ohm)
    [RailLink-CSV_inch.csv, RailLink-CSV_mm.csv, RailLink.kicad_pcb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]
2020-09-05 Added Elsys adapter
    [RailLink_Elsys_Adapter-B_Cu.gbr, RailLink_Elsys_Adapter-B_Mask.gbr, RailLink_Elsys_Adapter-B_SilkS.gbr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]
2020-09-22 Fixed B0505 footprint height, fixed Gerber grid origin, added solder paste Gerber files.
    [RailLink-B_Cu.gbr, RailLink-B_Mask.gbr, RailLink-B_Paste.gbp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]
2020-09-24 refactor: Optimized the project structure. Created folders for different items
    [RailLink-CSV_inch.csv, RailLink-CSV_mm.csv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]
2020-09-24 new: Added source files of the device case project to SolidWorks 2019
    [M2.5x14.SLDPRT, asm-jlink-case.SLDASM, jlink-case-bottom.SLDPRT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]
2020-11-19 fix: Внес правки по корпусу после изготовления прототипа
    - сдвинул отверстие под светодиод на 0.25 мм и уменьшил его
    диаметр на 0.1 мм до 3.1 мм для более плотного расположения;
    - сделал радиаусы кратными 2 мм для снижения стоимости работ
    по фрезеровке корпуса
    [asm-jlink-case.SLDASM, jlink-case-bottom.SLDPRT, jlink-case-bottom.STEP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]
